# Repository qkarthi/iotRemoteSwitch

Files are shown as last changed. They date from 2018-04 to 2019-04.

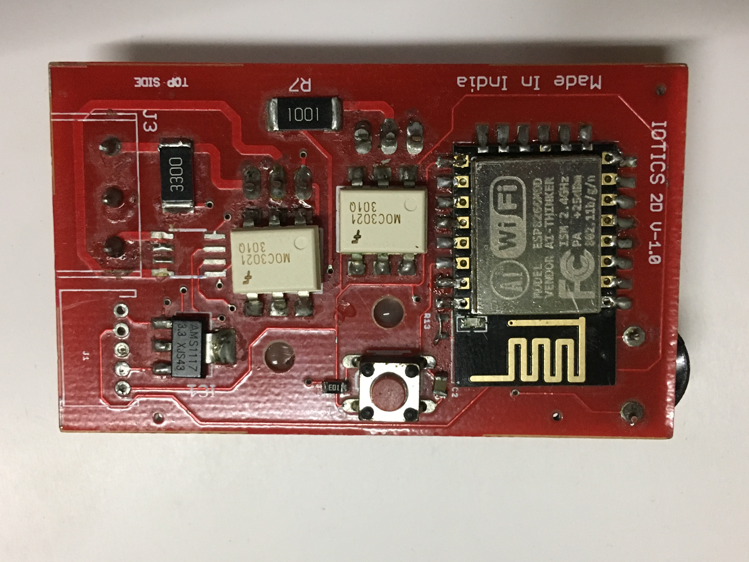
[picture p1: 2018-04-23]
docs/hardware_photos/esp_side.jpg

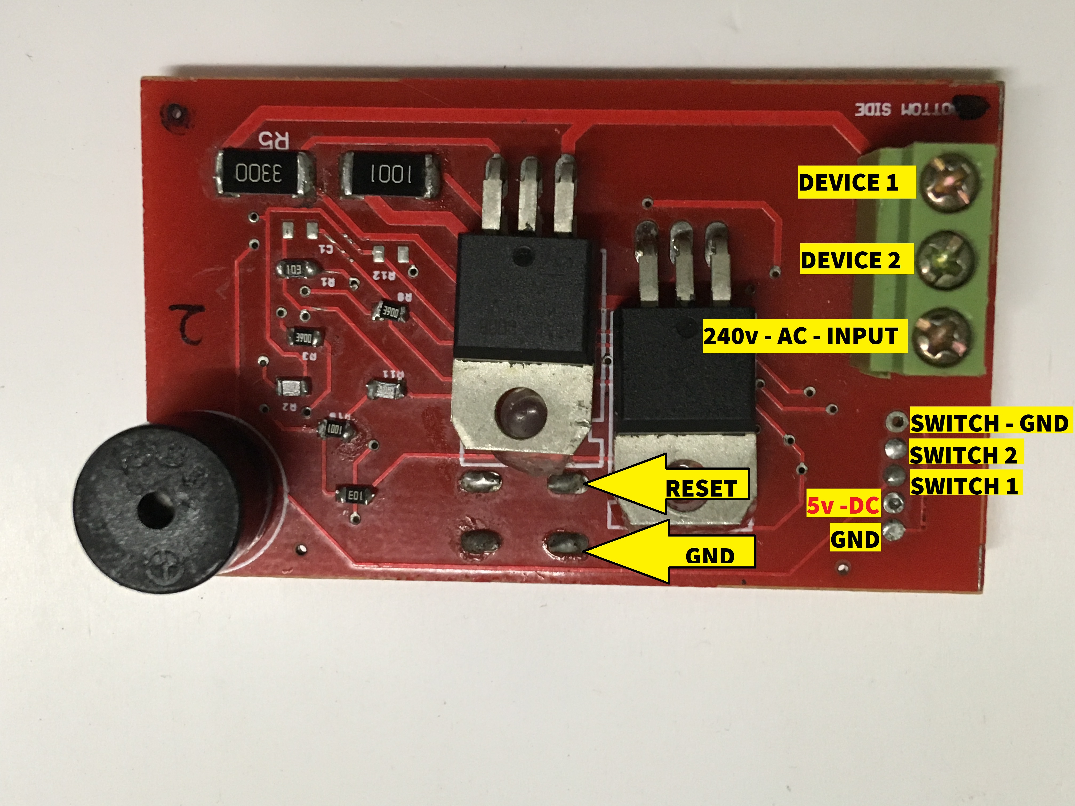
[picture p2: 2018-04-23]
docs/hardware_photos/triac_side.jpg

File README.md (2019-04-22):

## Project Details:
- Project name : `switcher`
- Version : v1.0 - (DEVELOPEMENT PHASE - ALPHA)
- Description : IOT based lights-on-off controller.
- Documentation date : 18-04-2018 .
- Documented by : Karthikeyan.p - product engineer (2018), qkarthi@gmail.com

## Programming Details:
- MCU_1 : esp8266-12e
  - Bootloader : NODE-MCU-1.0 ( ESP-12E module )
  - Upload speed : 115200
  - Flash size : 4M(1M SPIFFS)
  - cpu frequency : 80Mhz
  - software defined programmer : AVRISP MKII

## Hardware pin details:
- MCU_1 : esp8266-12e - Hardware pins:
  ```
  RST - (NO PURPOSE)
  ADC- ACS_712
  EN - (NO PURPOSE)
  [*]	gpio16 - D1_OUT
  [*]	gpio14 - D2_OUT
  [*]	gpio12 - D1_SWITCH
  [*]	gpio13 - D2_SWITCH
  VCC - (NO PURPOSE)
  CSO - (NO PURPOSE)
  MISO - (NO PURPOSE)
  gpio9 - (NO PURPOSE)
  gpio10 - (NO PURPOSE)
  MOSI- (NO PURPOSE)
  SCLK- (NO PURPOSE)
  [*]	TXD0- RX of MCU_2
  [*]	RXD0- TX of MCU_2
  gpio5 - RESET-FACTORY_MODE
  gpio4 - BUZZER
  gpio0 - (NO PURPOSE)
  gpio2 - (NO PURPOSE)
  gpio15 - (NO PURPOSE)
  GND - (NO PURPOSE)
  ```
*( NOTE : basic and minimal circuit is necessory , please see the circuit diagram , the purpose only mentioned above!)*

- MCU_1 : esp8266-12e - {BLYNK} Virtual pins:
    ```
		Device detail
		V2 - rssi

		Device control
		v11 - device 1 on/off button
		V12 - device 2 on/off button
		v19 - master power on button
		V20 - master power off button

		Device schedule
		v21 - scheduler 1 activation button
		V22 - scheduler 2 activation button
		v51 - scheduler 1 timer
		V52 - scheduler 2 timer
		v71 - scheduler 1 device selector
		V72 - scheduler 2 device selector

		Device name
		v31 - device 1 name
		V32 - device 2 name

		Additionals
		v111 - ota
		V99 - terminal
		
		Properatory
		v100 - internal ota
	```	

## IDE deatails :
- IDE name : ARDUINO
- IDE version : 1.8.5

## Other software dependencies detail :
#### ESP8266 :
- esp8266 library details :
  ```
  github : https://github.com/esp8266/Arduino
  version : 2.4.0-rc2
  ```
- blynk library details :
  ```
  github : https://github.com/blynkkk/blynk-library
  version : 0.5.2
  ```
- fauxmaESP library :
  ```
  bitbucket : https://bitbucket.org/xoseperez/fauxmoESP
  version : 2.4.2
  ```

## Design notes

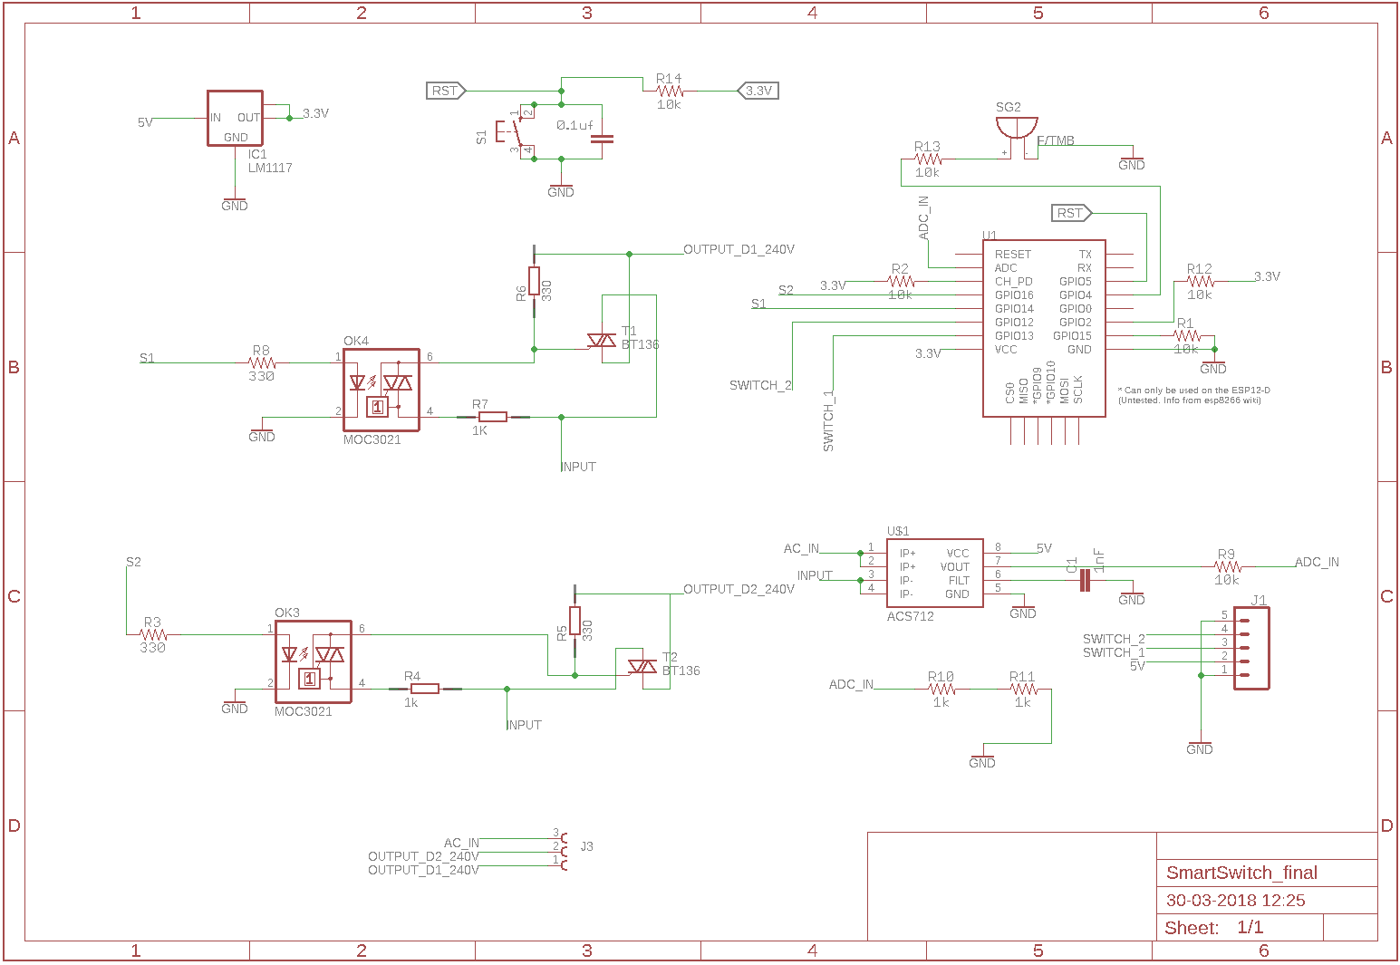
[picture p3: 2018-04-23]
docs/schematics_and_board/board_smart_switch.png

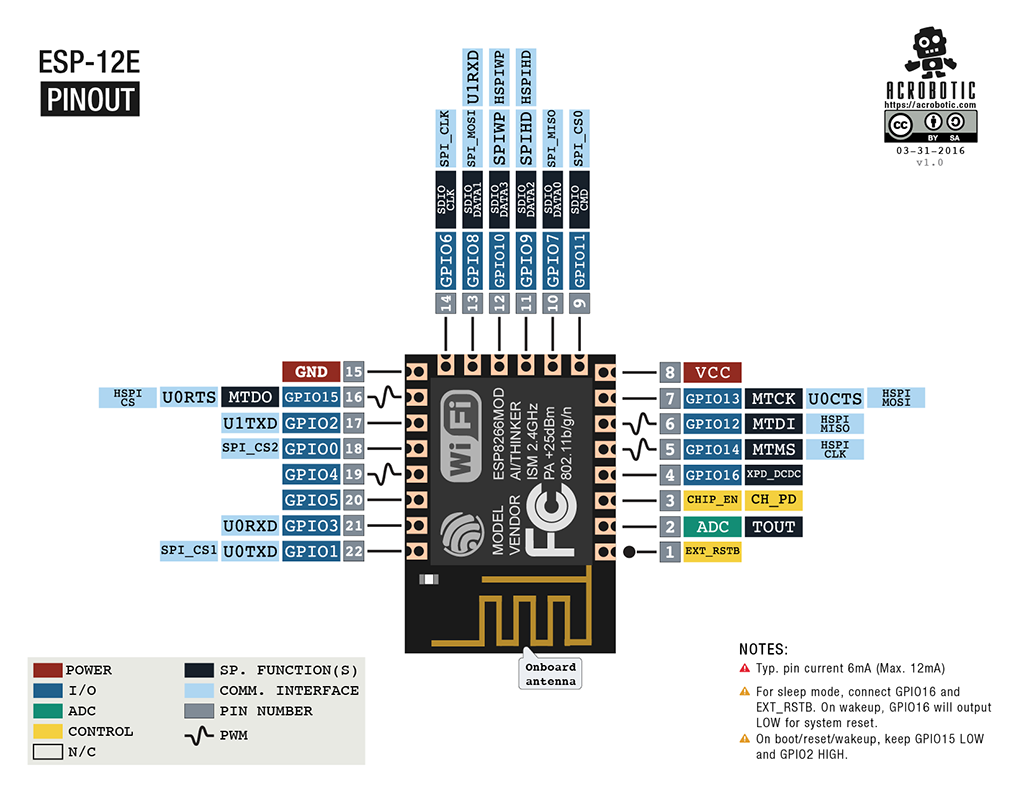
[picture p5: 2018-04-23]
docs/developer_board_images/esp8266_esp12e_detailed.png

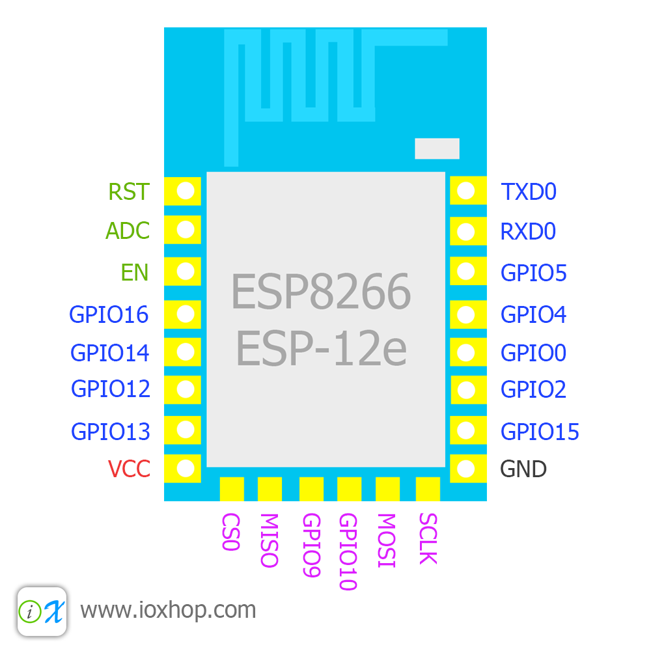
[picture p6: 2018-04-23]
docs/developer_board_images/esp_8266_12e.png

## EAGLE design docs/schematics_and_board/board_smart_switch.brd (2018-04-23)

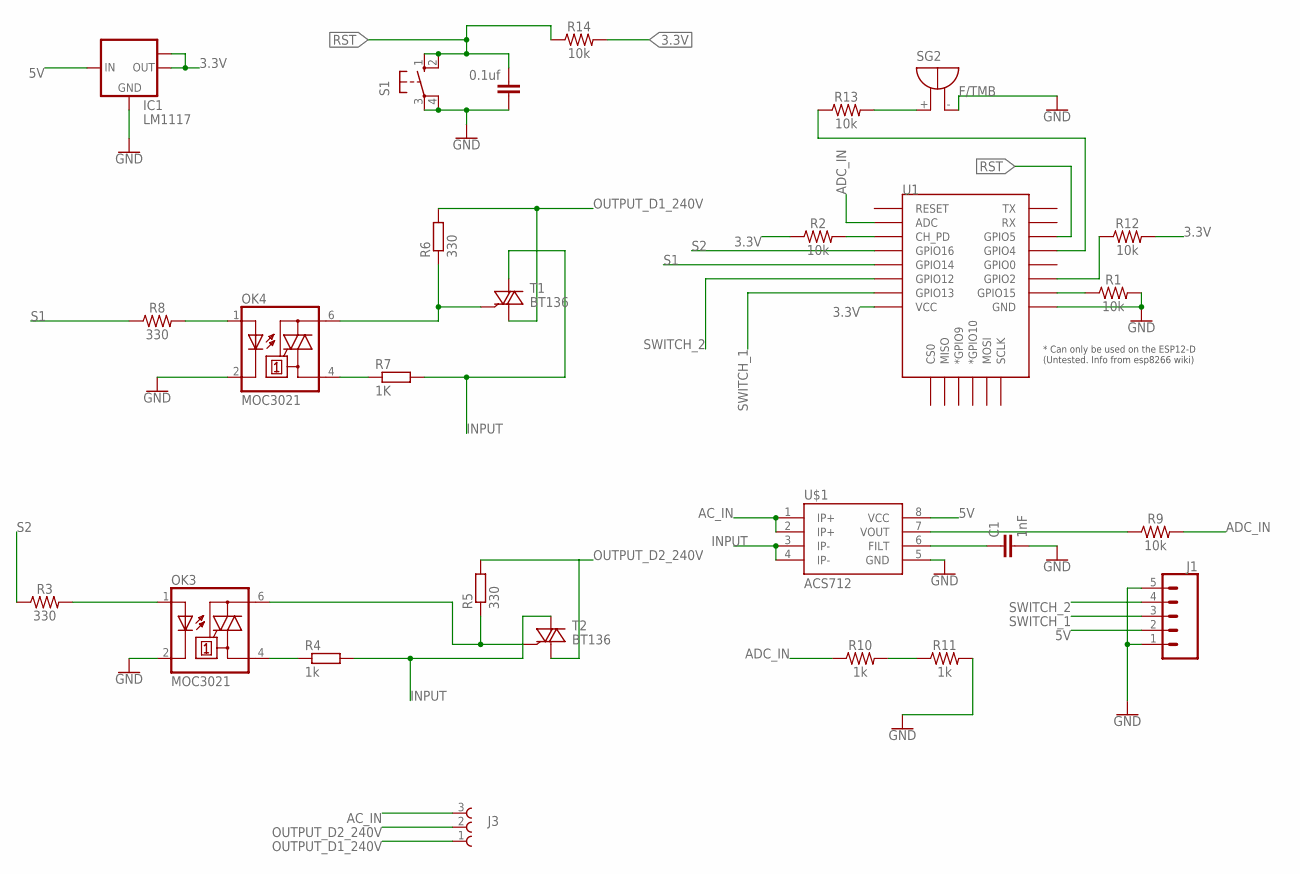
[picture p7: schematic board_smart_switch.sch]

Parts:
C1: 1nF; 0805
C2: 0.1uf; 0805
IC1: LM1117; SOT223
J1: CONN_05JST; JST-5-PTH
J3: 691104700003
OK3, OK4: MOC3021; DIL6-SMD
R1, R2, R9, R12, R13, R14: 10k; 0805
R3, R8: 330; 0805
R4: 1k; R2512
R5, R6: 330; R2512
R7: 1K; R2512
R10, R11: 1k; 0805
S1: 10-XX; B3F-10XX
SG2: F/TMB
T1, T2: BT136; TO220AB
U1: ESP12ESMD; ESP12E-SMD
U$1: ACS712; SO08

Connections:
3.3V: IC1.2 (OUT), IC1.TAB (OUT1), R2.1, R12.2, R14.2, U1.VCC
5V: IC1.3 (IN), J1.2, U$1.8 (VCC)
AC_IN: J3.3 (1), U$1.1 (IP+), U$1.2 (IP+)
ADC_IN: R9.2, R10.1, U1.ADC
GND: C1.2, C2.1, IC1.1 (GND), J1.1, J1.5, OK3.2 (C), OK4.2 (C), R1.2, R11.2, S1.3, S1.4 (P1), SG2.-, U1.GND, U$1.5 (GND)
INPUT: R4.2, R7.2, T1.2 (A2), T2.2 (A2), U$1.3 (IP-), U$1.4 (IP-)
unnamed: OK4.1 (A), R8.2
unnamed: OK3.1 (A), R3.2
unnamed: R2.2, U1.CH_PD
unnamed: R1.1, U1.GPIO15
unnamed: OK4.4 (A1), R7.1
unnamed: OK3.6 (A2), R5.1, T2.3 (G)
unnamed: C1.1, U$1.6 (FILT)
unnamed: OK3.4 (A1), R4.1
unnamed: OK4.6 (A2), R6.1, T1.3 (G)
unnamed: R9.1, U$1.7 (VOUT)
unnamed: R10.2, R11.1
unnamed: R12.1, U1.GPIO2
unnamed: R13.2, SG2.+
unnamed: R13.1, U1.GPIO4
OUTPUT_D1_240V: J3.1 (3), R6.2, T1.1 (A1)
OUTPUT_D2_240V: J3.2, R5.2, T2.1 (A1)
RST: C2.2, R14.1, S1.1 (S), S1.2 (S1), U1.GPIO5
S1: R8.1, U1.GPIO14
S2: R3.1, U1.GPIO16
SWITCH_1: J1.3, U1.GPIO13
SWITCH_2: J1.4, U1.GPIO12

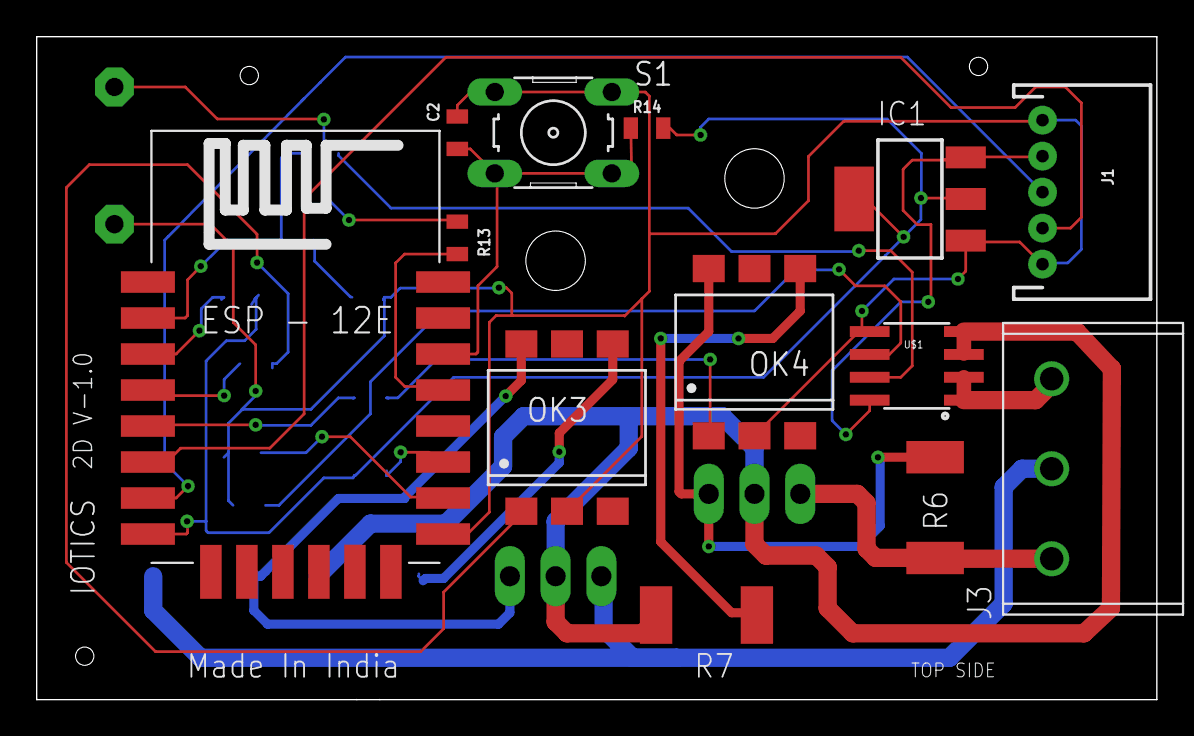
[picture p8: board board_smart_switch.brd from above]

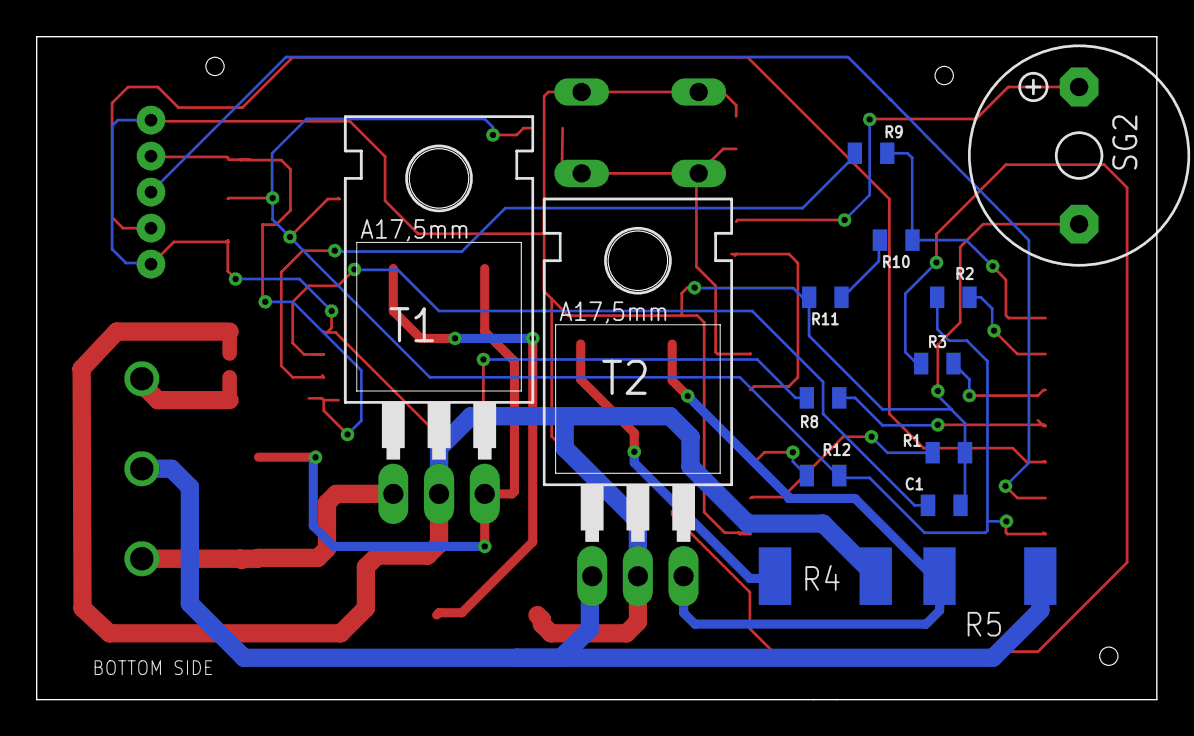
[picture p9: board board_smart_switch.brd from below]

Board: 2 copper layers, 62.2 x 36.8 mm, 27 parts (14 on the bottom side), 27 nets.

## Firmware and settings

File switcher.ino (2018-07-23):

#define APP_DEBUG
#define BLYNK_PRINT Serial

#include <BlynkSimpleEsp8266.h>
#include "BlynkProvisioning.h"
#include <TimeLib.h>
#include <WidgetRTC.h>
#define countof(a) (sizeof(a) / sizeof(a[0]))
//alexa header files
#include <WiFiUdp.h>
#include <functional>

WidgetRTC rtc; //declaring rtc for time getting from mobile
WidgetTerminal terminal(V99);  //declaring terminal
WidgetLED d1_led(V61), d2_led(V62); // declared led for device indcaation
//////////////////////////////////////////////////////
BlynkTimer d1_hw_switch_timer, d2_hw_switch_timer;
BlynkTimer conn_maint, upd_equipment_detail_timer;
BlynkTimer  scheduler_1_timer, scheduler_2_timer;
//////////////////////////////////////////////////////
String  client_id;
String TermString, TermCharOne, TermCharRest, TermTimeStr;
String lightOn_str = "\xe2\x97\x8f";
String lightOff_str = "\xe2\x97\x8b";
//////////////////////////////////////////////////////

int scheduler_1_var_1;
int scheduler_2_var_1;

int device_selected_scheduler_1;
int device_selected_scheduler_2;

long additional_scheduling_intervals = 9;
long scheduler_1_start_seconds;
long scheduler_2_start_seconds;

long scheduler_1_stop_seconds;
long scheduler_2_stop_seconds;
///////////////////////////////////////////
long nowseconds_var;
int dayadjustment_var;
int day_i;

/////////////////////////////////////////// !!!!!! Notes some variables are commented below ( because they are used as purpose in functionality under blynk_write function )

const int V_RssiPin = 2; // used for sending wifi signal to gauge

const int V_DStaStr = 5; // display the status

const int V_MasPowOnManButPin = 19;  // used for master power on below the device tiles
const int V_MasPowOffManButPin = 20; // used for master power off below the device tiles

const int V_D1ManButPin = 11;   // used as on off button for device 1
const int V_D2ManButPin = 12;   // used as on off button for device 2

//const int V_Sch1actButPin = 21;   // scheduer 1 activation button
//const int V_Sch2actButPin = 22;   // scheduer 2 activation button

const int V_D1Label = 31; //device 1 name pin
const int V_D2Label = 32; //device 2 name pin

//const int V_Sch1time_input = 51; //scheduler 1 time input pin
//const int V_Sch2time_input = 52; //scheduler 2 time input pin

//const int V_D1Led = 61; //device 1 Led pin
//const int V_D2Led = 62; //device 2 Led pin

const int V_DevSelector1 = 71; //device selector for scheduler 1 pin
const int V_DevSelector2 = 72; //device selector for scheduler 2 pin


//const int V_terminal = 99;  // terminal communication pin
//const int V_internal_otaButpin = 100;  // do not use this (100) because its only for sever based update method
//const int V_otaButpin = 111;  // it is used for user to update the device firm ware

const int V_colletive = 112;    // it is used for tile update .

///////////////////////////////////////////
bool FTC = true;
int d1_state;
int d1_hw_switch_1_state;

int d2_state;
int d2_hw_switch_1_state;
///////////////////////////////////////////
// alexa variables
//*************************************************************//
bool connectUDP();
void startHttpServer();
bool alexa_initiated = false;
///////////////////////////////////////////
// Some UDP / WeMo specific variables:
WiFiUDP UDP;
IPAddress ipMulti(239, 255, 255, 250);
int alx_port_d[3] = {0, 1001, 1002};
String serial, serialn;

unsigned int portMulti1 = 1900; // local port to listen on

ESP8266WebServer HTTP1(alx_port_d[1]);
ESP8266WebServer HTTP2(alx_port_d[2]);
String persistent_uuid; // Where we save some socket info with the UUID
char packetBuffer[UDP_TX_PACKET_MAX_SIZE]; // Buffer to save incoming packets:

char time_stamp_string[20];
//*************************************************************//
void setup() {
  Serial.begin(BAUD_RATE);
  DEBUG_PRINT("INFO - setup part started");
  client_id = String(WiFi.macAddress());

  delay(500);

  pinMode(d1_hw_switch_pin_1, INPUT_PULLUP); // declaring the pin as input-pullup
  pinMode(d2_hw_switch_pin_1, INPUT_PULLUP); // declaring the pin as input-pullup

  pinMode(d1_op_pin_1, OUTPUT); // declaring the pin as output
  pinMode(d2_op_pin_1, OUTPUT); // declaring the pin as output

  d1_hw_switch_1_state = digitalRead(d1_hw_switch_pin_1); // getting the state of hardware device 1 switch
  d2_hw_switch_1_state = digitalRead(d2_hw_switch_pin_1); // getting the state of hardware device 2 switch




  BlynkProvisioning.begin();


  DEBUG_PRINT("INFO - blynk begin finished");

  d1_state =  configStore.Dev_1_state;
  d2_state =  configStore.Dev_2_state;

  digitalWrite(d1_op_pin_1, d1_state);
  digitalWrite(d2_op_pin_1, d2_state);

  if (d1_hw_switch_1_state != configStore.Dev_1_swi) {
    d1_state = !d1_state;
    d1_update_func(1, d1_hw_switch_1_state);
  }

  if (d2_hw_switch_1_state != configStore.Dev_2_swi) {
    d2_state = !d2_state;
    d2_update_func(1, d2_hw_switch_1_state);
  }

  d1_hw_switch_timer.setInterval(500, upd_d1_hw_switch_1_func);// setting the hardware switch timer with regular interval
  d2_hw_switch_timer.setInterval(500, upd_d2_hw_switch_1_func);// setting the hardware switch timer with regular interval


  scheduler_1_timer.setInterval(5000, scheduler_1_func); // setting the device 1 timer with regular interval
  scheduler_2_timer.setInterval(5000, scheduler_2_func); // setting the device 2 timer with regular interval

  conn_maint.setInterval(60000, con_maint_func);

  upd_equipment_detail_timer.setInterval(10000, upd_equipment_detail_func);

  Serial.println(String(WiFi.macAddress()));

  prepareIds() ;

  DEBUG_PRINT("INFO - setup completed");
}

void loop() {

  BlynkProvisioning.run();

  if (configStore.flagConfig) {
    d1_hw_switch_timer.run();
    d2_hw_switch_timer.run();

    scheduler_1_timer.run();
    scheduler_2_timer.run();

    conn_maint.run();
  }
  if (BlynkState::is(MODE_RUNNING) ) {
    upd_equipment_detail_timer.run();

    if (configStore.upnp_vars) {
      if (!alexa_initiated) {
        start_alexa();
        alexa_initiated = 1;
        DEBUG_PRINT("INFO - alexa initiated");
      }
      HTTP1.handleClient();
      HTTP2.handleClient();

      delay(1);
      parsePackets(); // If there are packets, we parse them:
      delay(10);
    }

  }
  CoR_PollCounterFunc();
}

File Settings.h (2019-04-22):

/*
   General options
*/

#define BOARD_FIRMWARE_VERSION        "1.1.0"
#define BOARD_HARDWARE_VERSION        "1.1.0"

#define BOARD_NAME                    "XXXXX"           // Name of your product. Should match App Export request info.
#define BOARD_VENDOR                  "XXXXX"           // Name of your company. Should match App Export request info.
#define BOARD_TEMPLATE_ID             "XXXXX"              
                                                               // PRODUCTION VERSION template .

#define PRODUCT_WIFI_SSID             "SW_V103"             // Name of the device, to be displayed during configuration. Should match export request info.
#define BOARD_CONFIG_AP_URL           "switcher.set"            // Config page will be available in a browser at 'http://our-product.cc/'

#define BOARD_BUTTON_PIN            16
#define BOARD_BUTTON_ACTIVE_LOW     false
#define BAUD_RATE                   9600
/*
   IOTICS Configuration
*/

#define PRODUCT_SHORTCODE            "switcher/io_sw_2d_v_1_0"               //This will be a uniquename without any spaces.
#define BOARD_ENV                    "development"                                  //Product environment should be development or production.
#define OTA_URL                      "http://firmware.s3.amazonaws.com"    //please check it if OTA not works.
//#define CURRENT_FIRMWARE             "io_sw_2d_v_1_0_3_11_06_2018_debug_v_1"                //Firware version will start from v.0.1 
#define CURRENT_FIRMWARE             "io2sw_v010-1607201819"

/*
   Advanced options
*/

#define BUTTON_HOLD_TIME_INDICATION   3000
#define BUTTON_HOLD_TIME_ACTION       10000

#define BOARD_PWM_MAX                 1023
////////////////////////////////////////////////////////////////////////////
#define WIFI_NET_CONNECT_TIMEOUT      10000 //<<-----<< CHECK HERE IF NETCONNECT ERROR (note : increase time)
////////////////////////////////////////////////////////////////////////////
#define WIFI_CLOUD_CONNECT_TIMEOUT    15000
#define WIFI_AP_CONFIG_PORT           80
#define WIFI_AP_IP                    IPAddress(192, 168, 4, 1)
#define WIFI_AP_Subnet                IPAddress(255, 255, 255, 0)
//#define WIFI_CAPTIVE_PORTAL_ENABLE

#define USE_TICKER
//#define USE_TIMER_ONE
//#define USE_TIMER_THREE

#if defined(APP_DEBUG)
#define DEBUG_PRINT(...) BLYNK_LOG1(__VA_ARGS__)
#else
#define DEBUG_PRINT(...)
#endif

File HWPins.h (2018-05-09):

//////////////////////////////////////////////basic hardwares pins are defined below

// buzzer = 4 - d2   <<<<<<<< SWITCHER VER.1.0.0 >>>>>>>>>>>
// reset = 5 - d1    <<<<<<<< SWITCHER VER.1.0.0 >>>>>>>>>>>

const int d1_op_pin_1 = 16; //d0 <<<<<<<< SWITCHER VER.1.0.0 >>>>>>>>>>>
const int d2_op_pin_1 = 14; //d5 <<<<<<<< SWITCHER VER.1.0.0 >>>>>>>>>>>

const int d1_hw_switch_pin_1 = 12; //d6 <<<<<<<< SWITCHER VER.1.0.0 >>>>>>>>>>>
const int d2_hw_switch_pin_1 = 13; //d7 <<<<<<<< SWITCHER VER.1.0.0 >>>>>>>>>>>

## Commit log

2017-09-12 error rectified on scheduling
    [Functionality.ino]
2017-09-14 kw hr calculation with reset
    [Functionality.ino]
2017-10-20 arduino and esp combination via serial slazer
2018-04-23 New repo initialized
    [IOTICS 2D V-1.0.brd, IOTICS 2D V-1.0.sch]
2018-05-04 Update iotics_switcher.ino to switcher.ino
2018-05-07 Refactor code for offline devices
2018-05-07 dump switch state to device
2018-05-08 last memory state of device retained
2018-05-08 switch state changer identification
2018-05-09 dump + last state + reset
    [DumpMode.h, Functionality.ino, HWPins.h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]
2018-05-09 timeout for ap mode correction
    [DumpMode.h]
2018-05-16 device s=tiles status fixed
    [Functionality.ino, Settings.h]
2018-05-22 hard code for single device
2018-05-22 device show for upnp
2018-05-22 working for one device - cleaned after removing wrong functions
    [alexa.ino, switcher.ino]
2018-05-23 alexa working with blynk for 2 devices
2018-05-24 updated wemo switch serial number
2018-05-29 device renaming via text box
2018-07-16 vendor,board,firmware changed
2019-04-22 migrated to github
    [board_smart_switch.brd, board_smart_switch.sch]

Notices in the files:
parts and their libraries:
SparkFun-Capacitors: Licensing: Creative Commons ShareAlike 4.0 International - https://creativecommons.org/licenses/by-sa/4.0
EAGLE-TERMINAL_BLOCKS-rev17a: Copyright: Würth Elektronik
